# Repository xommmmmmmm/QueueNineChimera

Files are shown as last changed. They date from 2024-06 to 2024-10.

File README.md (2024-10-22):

# Q9 Chimera & Limousine

Q9 Chimera & Limousine are RP2040-based, drop-in, multi-layout replacement PCBs for Keychron Q9. Chimera supports ortholinear layout with central or right-hand numpad, and traditional row-stagger with right hand numpad. Limousine supports row and alpha stagger, with support for 2.25u/2.75u "Alice" bars and right-hand numpad.

Both versions support up to two independent EC11 rotary encoders in the separated key positions, and a plethora of bottom-row options.

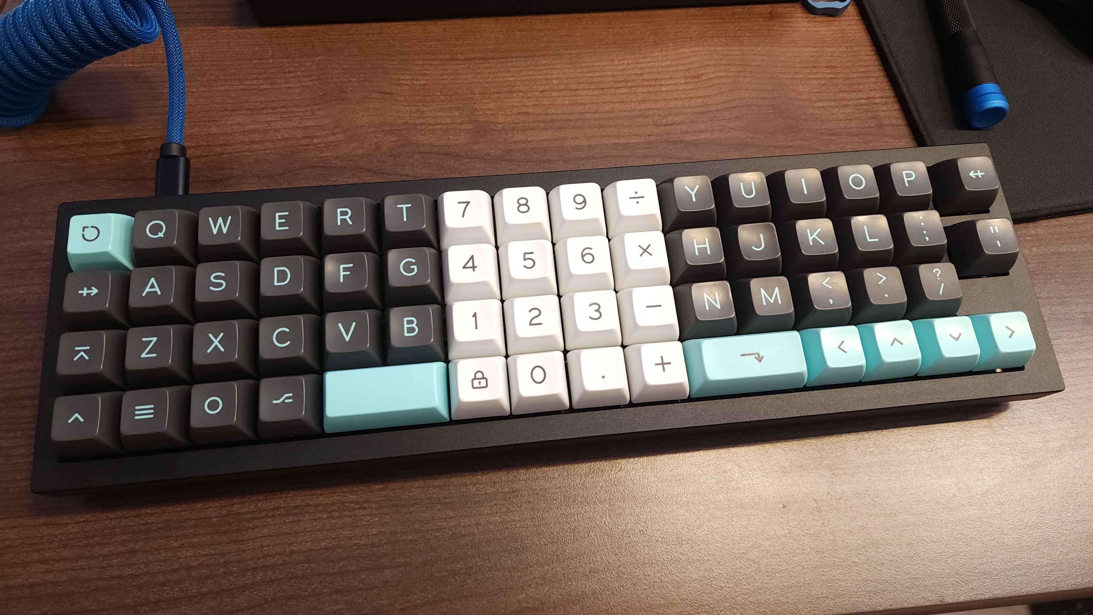
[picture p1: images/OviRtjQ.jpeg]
Q9 Chimera Ortho

*xomm's split ortho build*

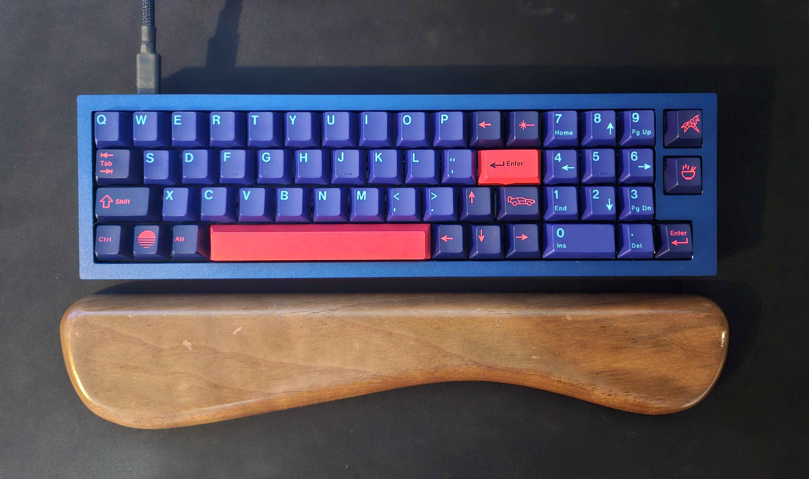
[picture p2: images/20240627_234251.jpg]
Q9 Chimera Row Stagger

*baconspoon's row-staggered build*

## Hardware

* Keyboard Maintainer: [xomm](https://github.com/xommmmmmmm) and [baconspoon](https://github.com/baconspoon85)
* Hardware Supported: Keychron Q9, Keychron Q9 Plus cases with Q9 Chimera PCB
* Hardware Availability: Case from [Keychron](https://www.keychron.com/products/keychron-q9-qmk-custom-mechanical-keyboard), Open-source PCB orderable from JLCPCB using provided production files in their respective subfolders. Production files should be orderable as-is and have been used successfully for PCBA, but no guarantees or warranties are made. 

This project is not affiliated with or endorsed by Keychron or JLCPCB.

### Build Guide

**Disassembly**:
1. If you have keycaps on the board, remove them before disassembly to avoid scratching them against the case.
1. Flip the board upside down and unscrew the six H2.5 screws on the bottom case to remove it.
1. Disconnect the JST connector from the original board
1. Lift the assembly out by lifting from the bottom (spacebar side) first, then pull it out from under the daughterboard. Take care not to lose the 3 plastic caps from the pegs on the top case.

**Test the new PCB**:
1. Insert 2 switches in the top left for unlocking the board.
1. Connect the JST from the daughterboard to the new board.
1. Taking care to not short any board components on the top case, connect the USB-C to your PC.
1. Open https://vial.rocks/ to validate that it is detected.
1. Open the matrix tester and use tweezers or a switch puller to check sockets.
1. Disconnect USB-C once done, then disconnect the JST.

**PCB Assembly**:
1. If you have a barebones PCB and/or want to add EC11 encoder(s), now is the time to solder. 
    1. If you are not using encoder(s), and you originally purchased the Q9 with one, remove the PH1 screws holding in the encoder blocker from the top case. 
1. Add any PCB-mounted stabilizers you will be using. If your switches have minimal wobble, you generally won't need 2u stabilizers.  
    1. Limousine note: If you chose to have Mill-Max sockets soldered for 3u spacebars, you will need to desolder one of the Kailh hotswap sockets to access a 3u stabilizer hole. Conversely, the 3u Mill-Max sockets sit under the stabilizers of other footprints, so you may want to add pads under your stabilizers to reduce the bottom-out noise.

**Plate Assembly**:
1. When inserting switches, support the hotswap socket from the back to avoid accidental damage in case of misalignment. Reference the KLE for your desired layout if unsure which footprints to use.
1. To align the plate, place switches around the border of the plate and a few in the top row, then assemble the plate to the PCB.
1. To minimize plate flex when inserting switches, fill out the remaining switches from right to left, top to bottom.
1. If you will be reusing the original foam gaskets, remove them carefully by picking at one side until all the adhesive is lifted, then slowly peel it off the plate.
1. If you will be using the included gaskets from the kit, they are unfortunately short, but will function and sound pretty much the same.
    1. You can choose to use them as-is and stick them in the middle, or cut them in half and stick them on the edges.
1. Apply the gaskets on both sides of the plate (eight total), using tweezers is recommended.

**Case Assembly**:
1. Insert the assembly into the top case, putting the top under the daughterboard first, then aligning the mounting holes on the plate with the pegs in the top case. Pay attention to the six screw posts since they might catch on their cutouts in plate a bit. There might be a little bit of friction at first but it will seat once everything is aligned, heavy force is not required. 
1. Tape modding the bottom of the PCB or the inside of the bottom case, either with the stock cardboard adhesive and/or 3M painter's tape is highly recommended. This will prevent unlikely but possible shorts from bottoming out the PCB on aftermarket gaskets if you press hard.
1. Close the bottom case, add keycaps, set up your layout in Vial.
    1. In Vial, use the Layouts tab to select the physical layout options you want. For the 8u/10u spacebar option on Chimera v1.1, select the first 6u bar option and simply leave the unused keys blank.
3. Enjoy! (And maybe send a pic of your completed build in the mini-GB channel on the 40% Keyboards Discord server!)

## Firmware

PCBs purchases from the mini-GB are pre-flashed. Vial firmware source can be found [here](https://github.com/xommmmmmmm/vial-qmk/tree/q9_chimera_v1.1/keyboards/q9_dropin). Pre-compiled firmware can be found [here](https://github.com/xommmmmmmm/QueueNineChimera/tree/main/firmware/). 

# Q9 Chimera keymap options

All sockets for all layout options can be populated during PCB assembly, including the ones under the encoders.

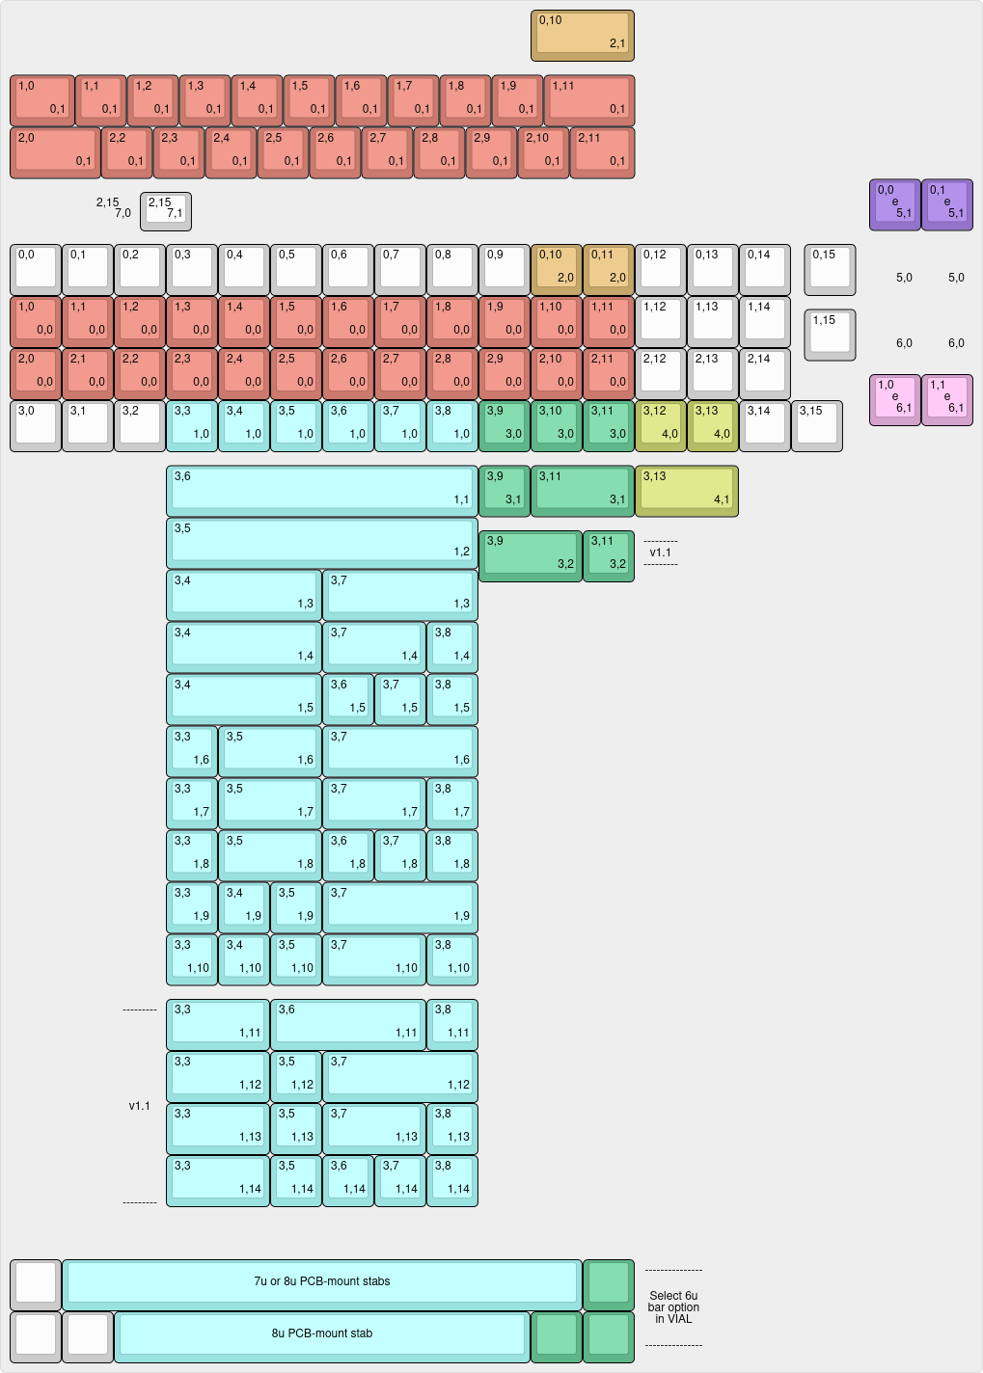
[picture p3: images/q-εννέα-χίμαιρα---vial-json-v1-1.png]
Q9 Chimera v1.1 keymap options

- [Chimera v1.0 Keyboard Layout Editor gist](https://www.keyboard-layout-editor.com/#/gists/b5c5bf3bcd11c2a14bd86eb9c05d4cf7)
- [Chimera v1.1 Keyboard Layout Editor gist](https://www.keyboard-layout-editor.com/#/gists/ead72f9d526c6d2558d7e2d7f39707f8)

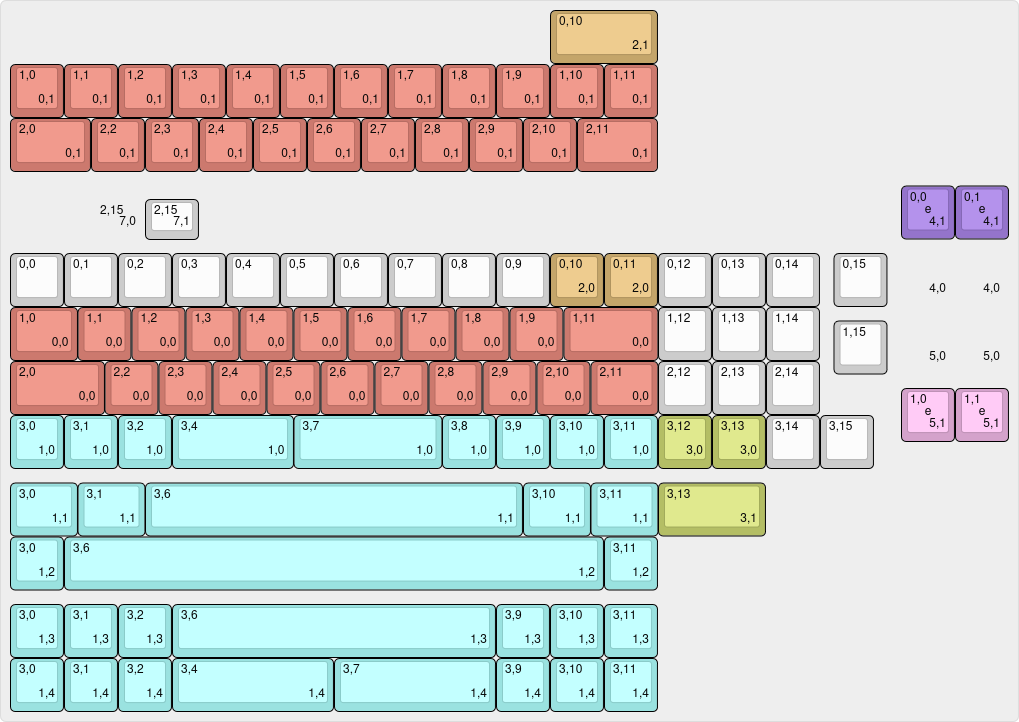
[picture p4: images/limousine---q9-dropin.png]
Q9 Limousine v1.0 keymap options

- [Limousine v1.0 Keyboard Layout Editor gist](https://www.keyboard-layout-editor.com/#/gists/2bb4640f105051db48f84b30d6797b1b)

## Options

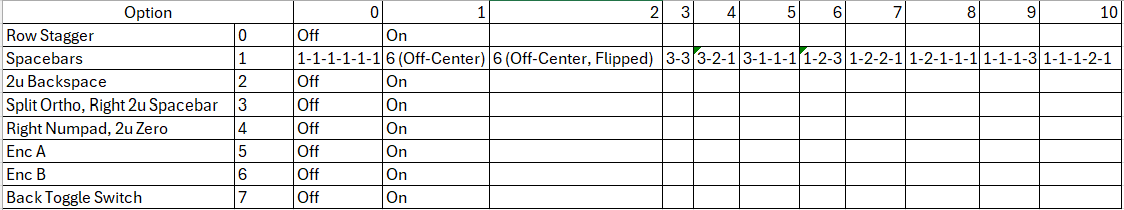
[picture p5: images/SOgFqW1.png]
Q9 Chimera keymap option names


The images at the top use the following options:
- xomm's split ortho layout:
  - Spacebar option 8: 1-2-1-1-1
  - Split Ortho, Right 2u Spacebar
- baconspoon's row-staggered layout:
  - Row Stagger
  - Spacebar option 2: 6 (off-center, flipped)
  - Right Numpad, 2u Zero

The default keymap is provided as barebones due to the number of possible layouts, and should be edited as desired. Remember to export your .vil from Vial GUI once satisfied for safekeeping.

## Credits and helpful things

- Big thanks to baconspoon for validating the design, contributing plate/edge cuts, additional layouts, and a ton of other help.
- Noah Kiser's [TKL RP2040 PCB Design](https://www.youtube.com/watch?v=6Z49bynRqj8&list=PLstjCi968EZftHZSitvqiVnyZ1CbmptIB) series
- Joe Scotto's [PCB Design](https://www.youtube.com/watch?v=7LyziNdFlew&list=PLBD2IS_t_iWZDMdG_ZF57x9Ebm3kxKqxF) series

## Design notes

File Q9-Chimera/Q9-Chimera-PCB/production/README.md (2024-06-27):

# JLCPCB Order Information

These were the settings used for the original production run for personal use. The PCB files have been updated since the first run to correct some solder mask issues based on JLC engineers' advice, and should be able to be ordered as-is, but no guarantees or warranties are made.

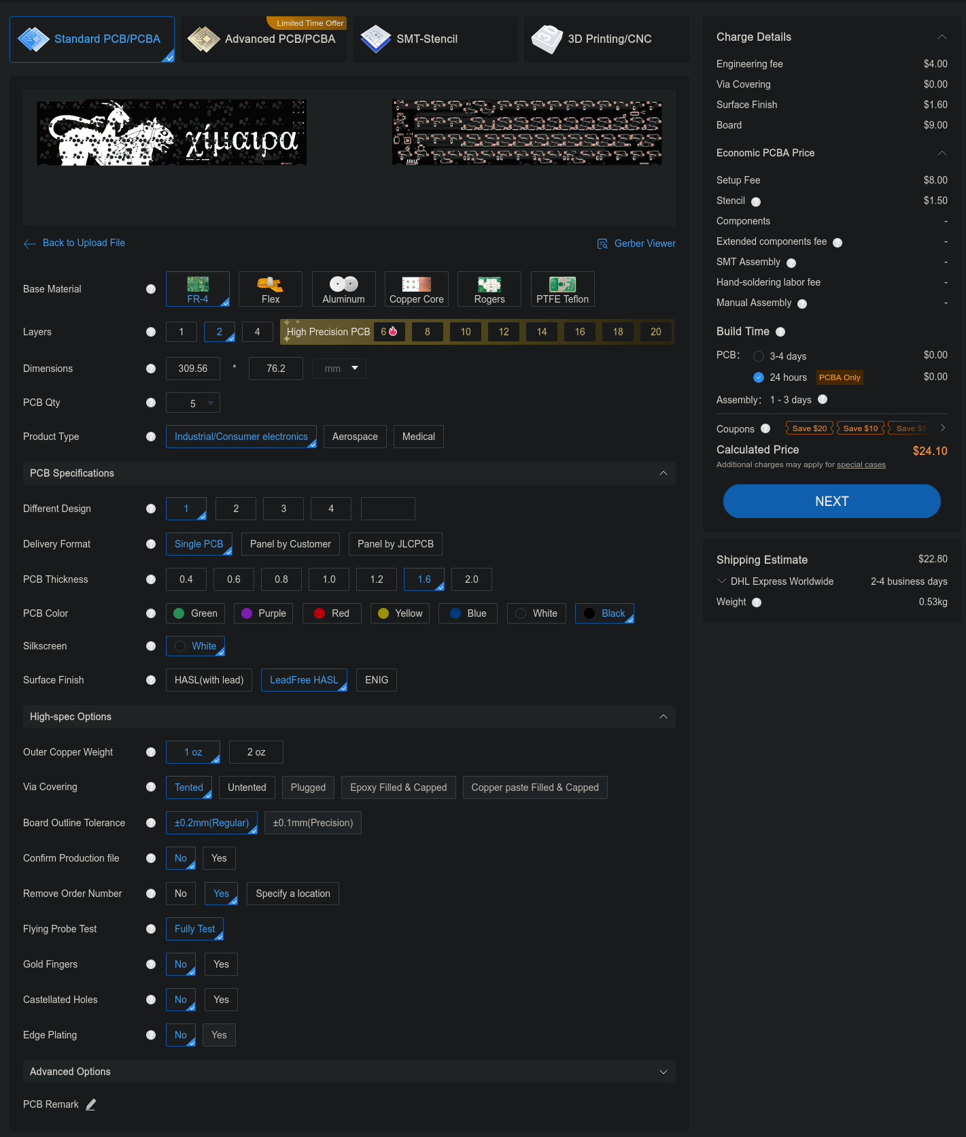
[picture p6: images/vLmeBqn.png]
JLCPCB1

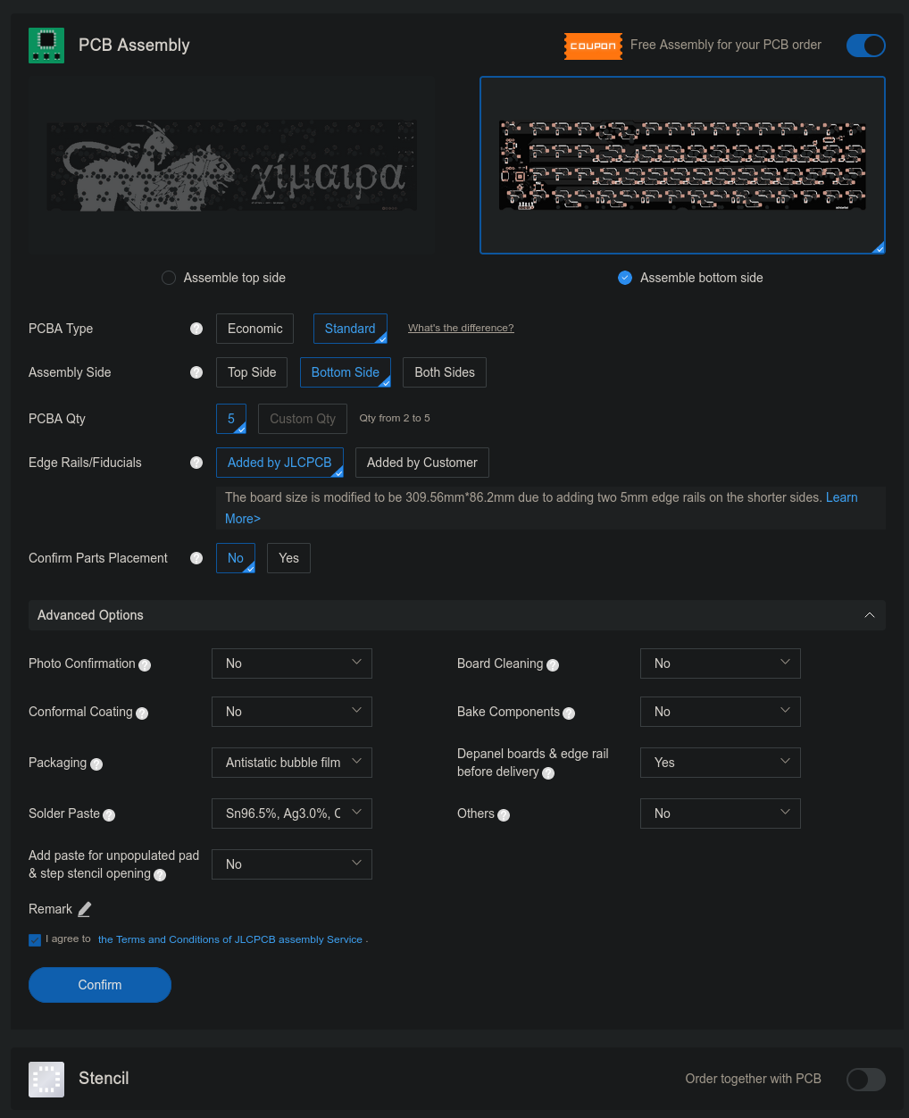
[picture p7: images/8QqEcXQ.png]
JLCPCB2

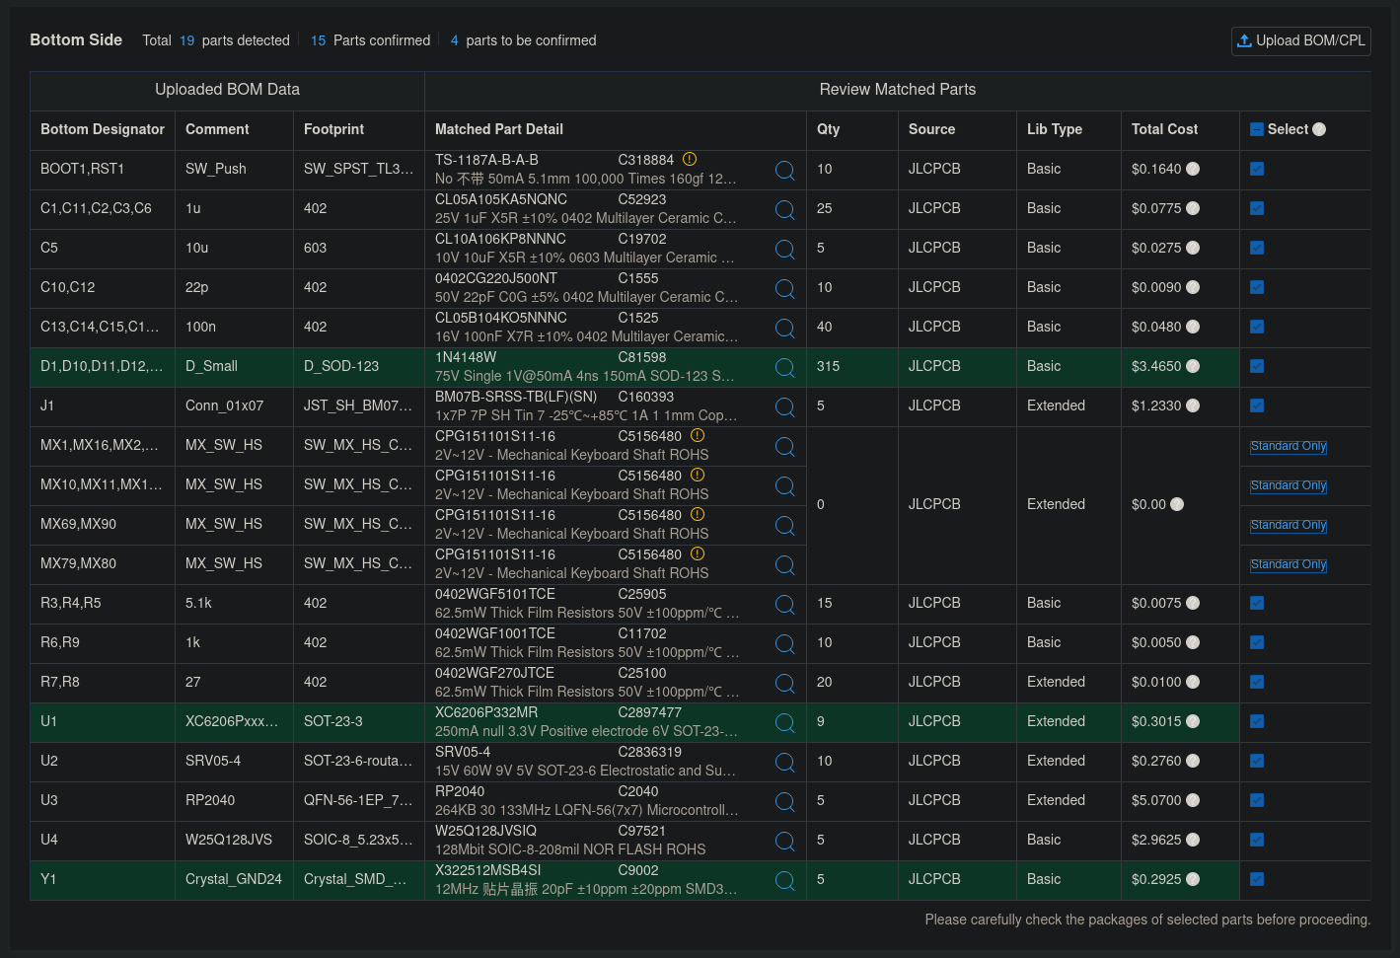
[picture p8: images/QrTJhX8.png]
JLCPCB3

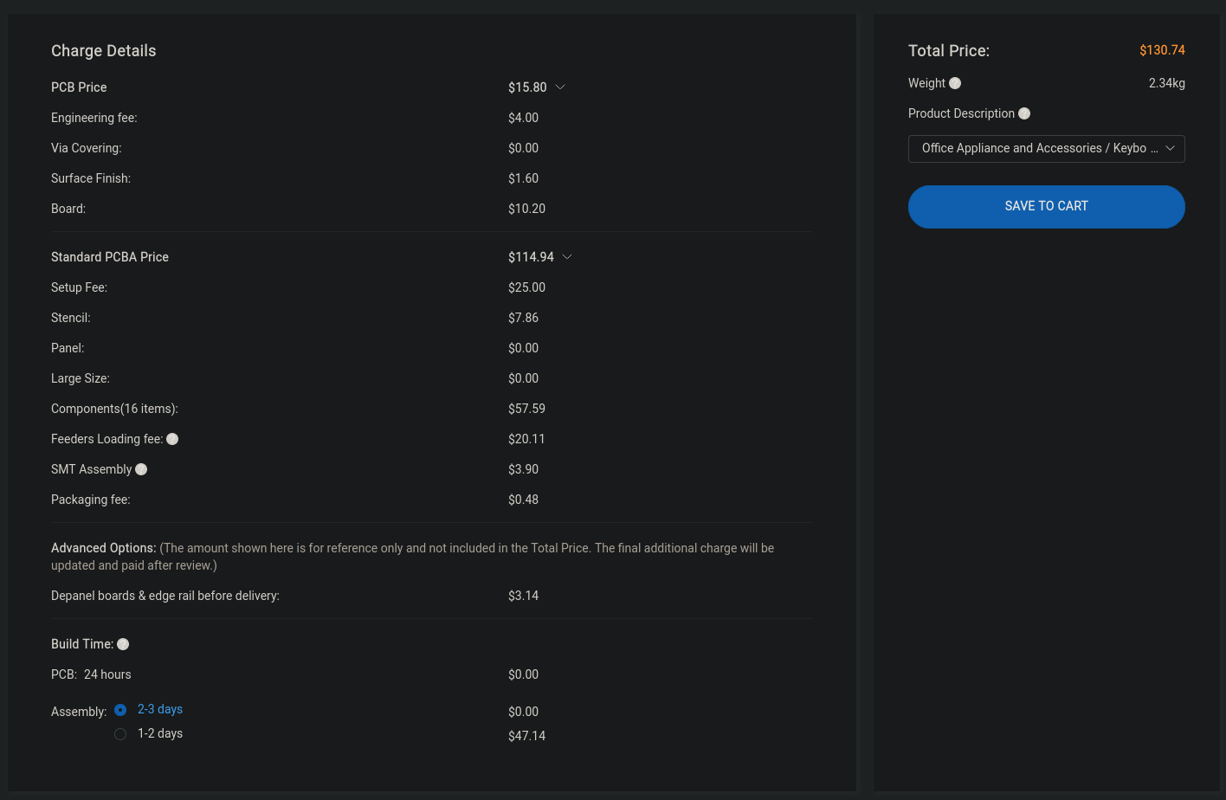
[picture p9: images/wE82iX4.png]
JLCPCB4


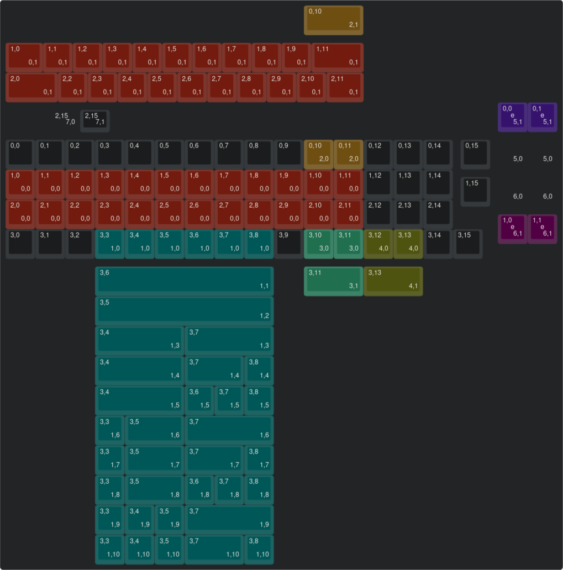
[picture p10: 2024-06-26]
images/q-εννέα-χίμαιρα---vial-json.png

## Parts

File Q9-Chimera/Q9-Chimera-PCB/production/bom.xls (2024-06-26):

Comment | Designator | Footprint | JLCPCB Part #
D_Small | D1,D10,D11,D12,D13,D14,D15,D16,D17,D18,D19,D2,D20,D21,D22,D23,D24,D25,D26,D27,D28,D29,D3,D30,D31,D32,D33,D34,D35,D36,D37,D38,D39,D4,D40,D41,D42,D43,D44,D45,D46,D47,D48,D49,D5,D50,D51,D52,D54,D55,D56,D57,D58,D59,D6,D61,D62,D63,D64,D65,D7,D8,D9 | D_SOD-123 | C81598
SW_Push | BOOT1,RST1 | SW_SPST_TL3342 | C318884
SRV05-4 | U2 | SOT-23-6-routable | C2836319
10u | C5 | 603 | C19702
Crystal_GND24 | Y1 | Crystal_SMD_3225-4Pin_3.2x2.5mm | C403945
27 | R7,R8 | 402 | C25100
MX_SW_HS | MX79,MX80,MX69,MX90,MX10,MX11,MX12,MX13,MX14,MX15,MX17,MX18,MX19,MX20,MX21,MX22,MX23,MX24,MX25,MX26,MX27,MX28,MX29,MX30,MX31,MX33,MX34,MX35,MX36,MX37,MX38,MX39,MX4,MX40,MX41,MX42,MX43,MX44,MX45,MX46,MX47,MX48,MX49,MX5,MX50,MX51,MX52,MX53,MX54,MX55,MX56,MX57,MX58,MX59,MX6,MX60,MX61,MX62,MX63,MX64,MX65,MX66,MX67,MX68,MX7,MX70,MX71,MX72,MX73,MX74,MX75,MX76,MX77,MX78,MX8,MX81,MX82,MX83,MX84,MX85,MX86,MX87,MX88,MX89,MX9,MX1,MX16,MX2,MX3,MX32 | SW_MX_HS_CPG151101S11_1u | C5156480
XC6206PxxxMR | U1 | SOT-23-3 | C2897477
100n | C13,C14,C15,C16,C4,C7,C8,C9 | 402 | C1525
22p | C10,C12 | 402 | C1555
5.1k | R3,R4,R5 | 402 | C25905
1u | C1,C11,C2,C3,C6 | 402 | C52923
Conn_01x07 | J1 | JST_SH_BM07B-SRSS-TB_1x07-1MP_P1.00mm_Vertical | C160393
W25Q128JVS | U4 | SOIC-8_5.23x5.23mm_P1.27mm | C97521
1k | R6,R9 | 402 | C11702
RP2040 | U3 | QFN-56-1EP_7x7mm_P0.4mm_EP3.2x3.2mm | C2040

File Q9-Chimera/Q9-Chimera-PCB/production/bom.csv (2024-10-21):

Designator | Footprint | Quantity | Value | LCSC Part #
BOOT1, RST1 | SW_SPST_TL3342 | 2 | SW_Push
C1, C11, C2, C3, C6 | 0402 | 5 | 1u
C10, C12 | 0402 | 2 | 22p
C13, C14, C15, C16, C4, C7, C8, C9 | 0402 | 8 | 100n
C5 | 0603 | 1 | 10u
D1, D10, D11, D12, D13, D14, D15, D16, D17, D18, D19, D2, D20, D21, D22, D23, D24, D25, D26, D27, D28, D29, D3, D30, D31, D32, D33, D34, D35, D36, D37, D38, D39, D4, D40, D41, D42, D43, D44, D45, D46, D47, D48, D49, D5, D50, D51, D52, D54, D55, D56, D57, D58, D59, D6, D61, D62, D63, D64, D65, D7, D8, D9 | D_SOD-123_xomm | 63 | D_Small
J1 | JST_SH_BM07B-SRSS-TB_1x07-1MP_P1.00mm_Vertical | 1 | Conn_01x07 | C160393
MX1, MX16, MX2, MX3, MX32 | SW_MX_HS_S_CPG151101S11_1u | 5 | MX_SW_HS
MX10, MX11, MX12, MX13, MX14, MX15, MX17, MX18, MX19, MX20, MX21, MX22, MX23, MX24, MX25, MX26, MX27, MX28, MX29, MX30, MX31, MX33, MX34, MX35, MX36, MX37, MX38, MX39, MX4, MX40, MX41, MX42, MX43, MX44, MX45, MX46, MX47, MX48, MX49, MX5, MX50, MX51, MX52, MX54, MX55, MX56, MX57, MX58, MX59, MX6, MX61, MX62, MX63, MX64, MX65, MX66, MX67, MX68, MX7, MX70, MX71, MX72, MX73, MX74, MX75, MX76, MX77, MX78, MX8, MX81, MX82, MX83, MX84, MX85, MX86, MX87, MX88, MX89, MX9, MX91, MX92 | SW_MX_HS_CPG151101S11_1u | 81 | MX_SW_HS
MX53, MX60, MX95 | SW_MX_1u | 3 | MX_SW_HS
MX69, MX90 | SW_MX_HS_CPG151101S11_1.25u | 2 | MX_SW_HS
MX79, MX80 | SW_MX_HS_CPG151101S11_1.75u | 2 | MX_SW_HS
R3, R4, R5 | 0402 | 3 | 5.1k
R6, R9 | 0402 | 2 | 1k
R7, R8 | 0402 | 2 | 27
S1, S2, S3, S4, S7, S8, S9 | STAB_MX_2u | 7 | MX_stab_2u
S10, S5, S6 | STAB_MX_3u | 3 | MX_stab_3u
S13 | STAB_MX_10u | 1 | MX_stab_7810u
U1 | SOT-23-3 | 1 | XC6206PxxxMR | C2897477
U2 | SOT-23-6-routable | 1 | SRV05-4 | C2836319
U3 | QFN-56-1EP_7x7mm_P0.4mm_EP3.2x3.2mm | 1 | RP2040 | C2040
U4 | SOIC-8_5.23x5.23mm_P1.27mm | 1 | W25Q128JVS | C97521
Y1 | Crystal_SMD_3225-4Pin_3.2x2.5mm | 1 | Crystal_GND24 | C403945

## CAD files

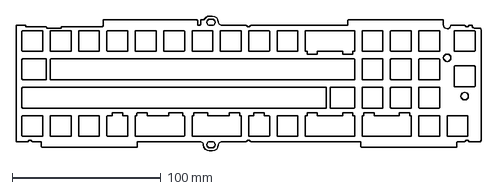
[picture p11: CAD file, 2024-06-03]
Q9-Chimera/Q9-Chimera-Plate/q9-chimera-plate.dxf
312.5 x 90.5 mm

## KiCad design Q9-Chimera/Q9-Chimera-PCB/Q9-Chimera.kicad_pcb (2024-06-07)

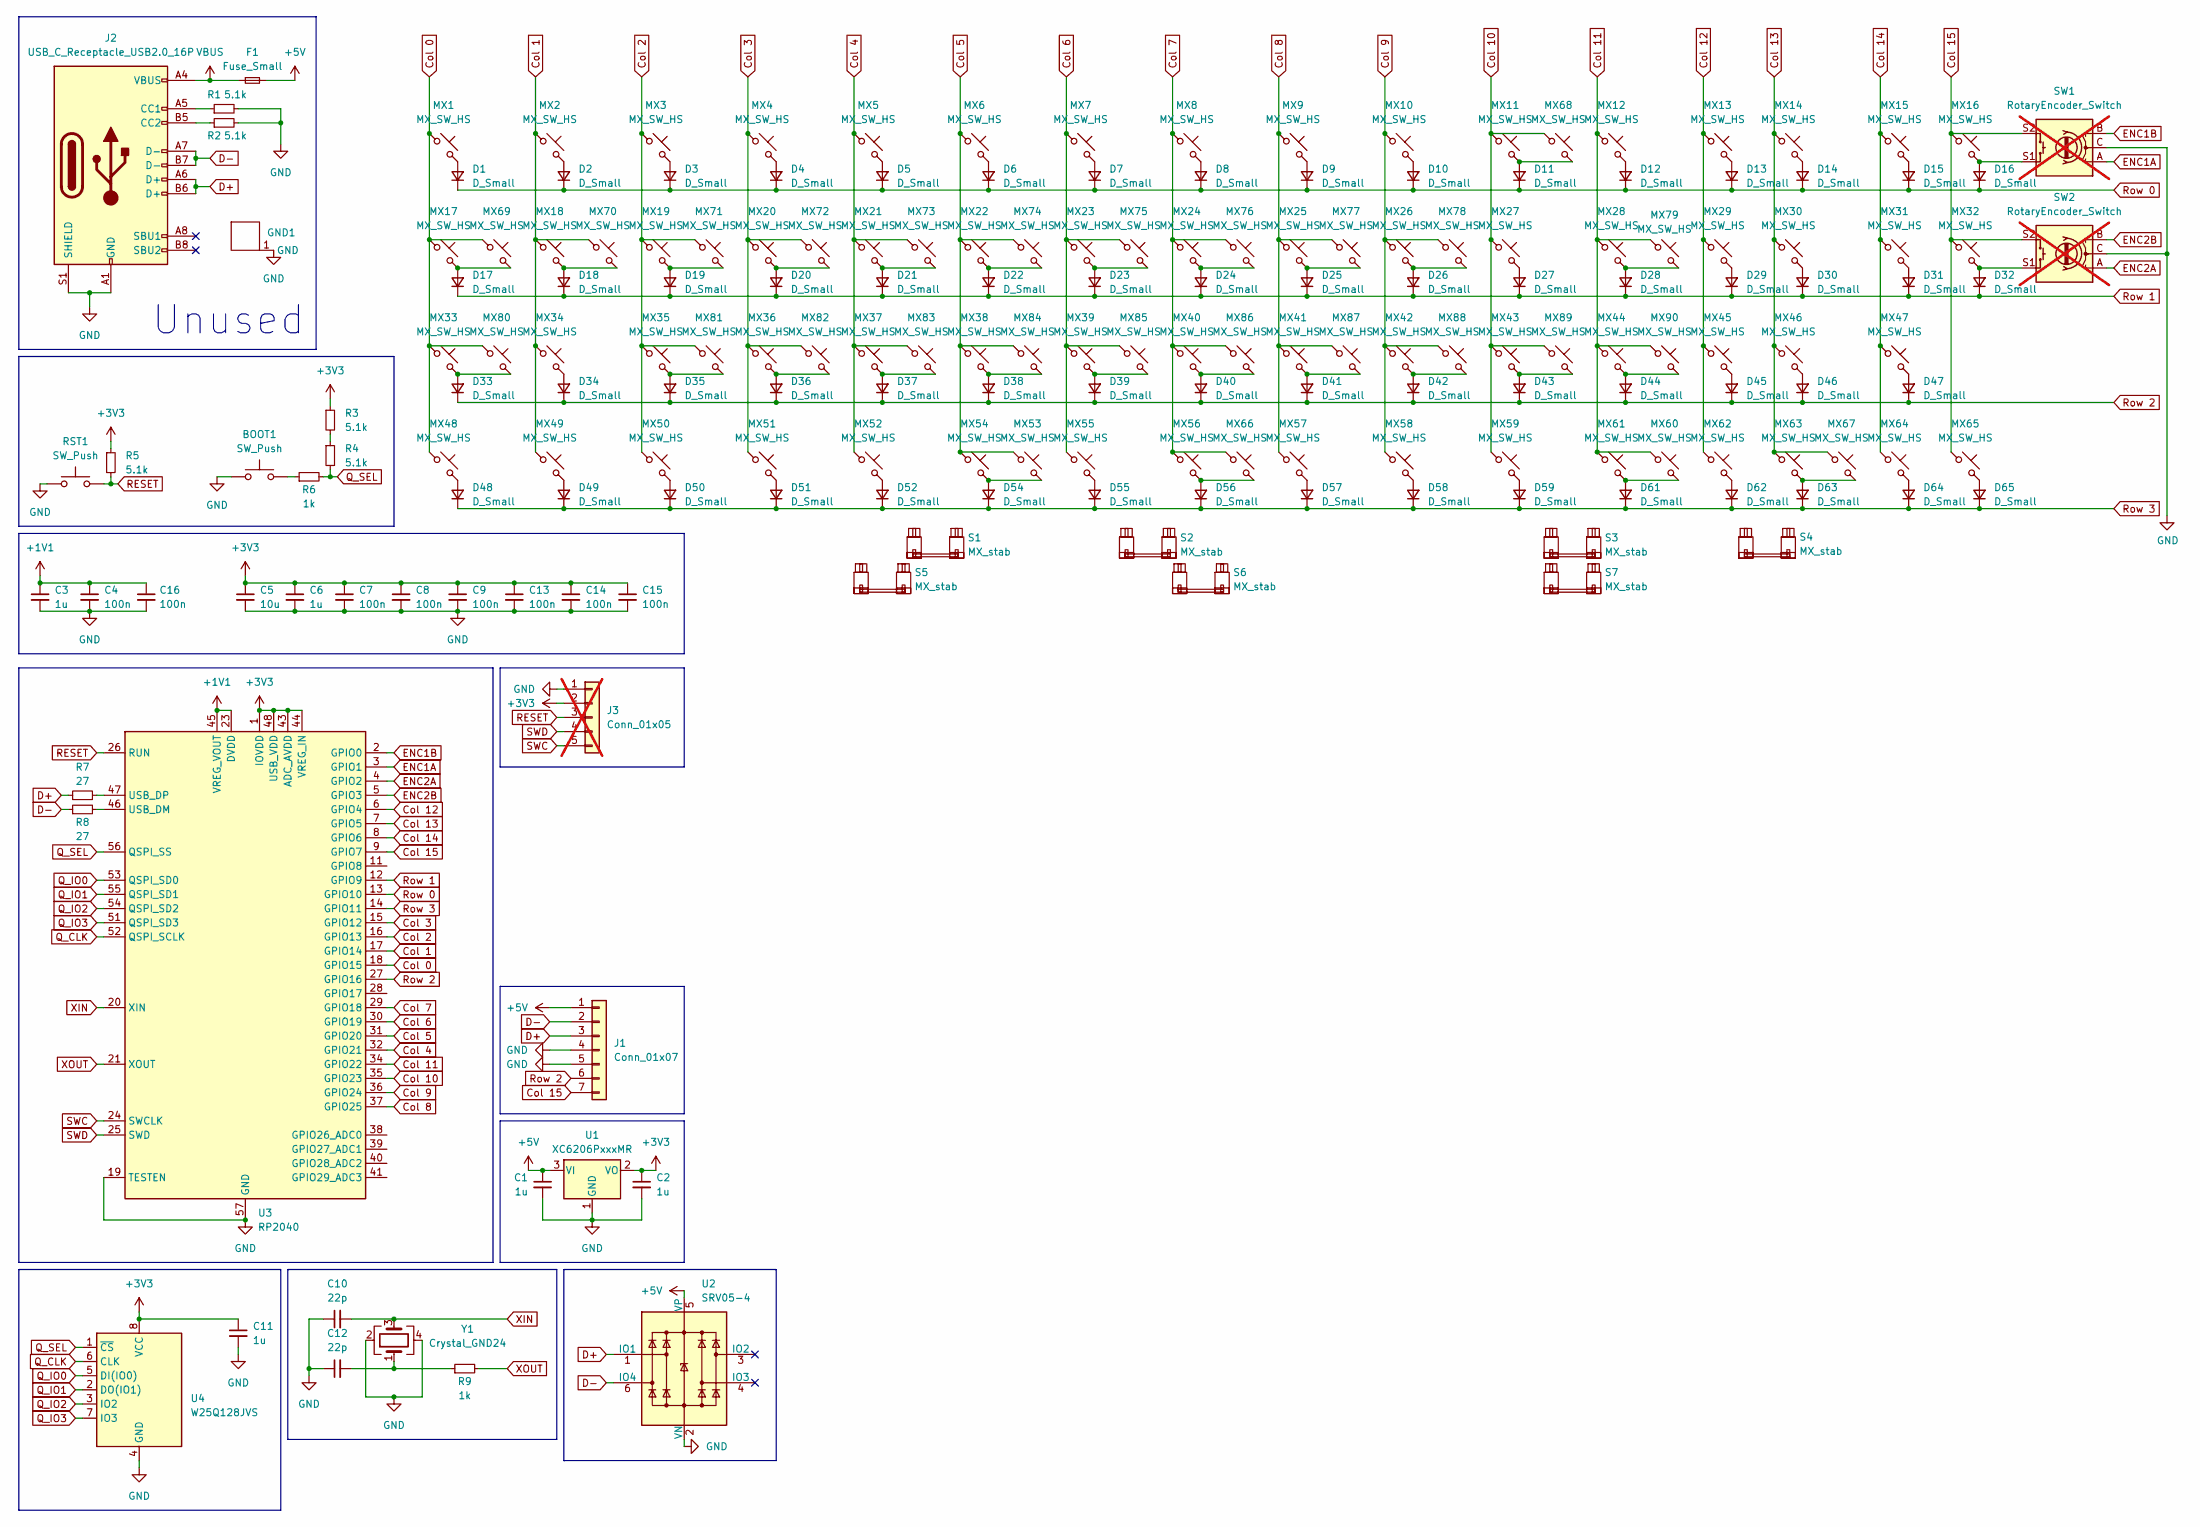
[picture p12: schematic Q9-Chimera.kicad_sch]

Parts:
BOOT1: SW_Push; SW_SPST_TL3342
C1, C2, C3, C6, C11: 1u; C_0402_1005Metric
C4, C7, C8, C9, C13, C14, C15, C16: 100n; C_0402_1005Metric
C5: 10u; C_0603_1608Metric
C10, C12: 22p; C_0402_1005Metric
D1, D2, D3, D4, D5, D6, D7, D8, D9, D10, D11, D12, D13, D14, D15, D16, D17, D18, D19, D20, D21, D22, D23, D24, D25, D26, D27, D28, D29, D30, D31, D32, D33, D34, D35, D36, D37, D38, D39, D40, D41, D42, D43, D44, D45, D46, D47, D48, D49, D50, D51, D52, D54, D55, D56, D57, D58, D59, D61, D62, D63, D64, D65: D_Small; D_SOD-123_xomm
F1: Fuse_Small; Fuse_1206_3216Metric
GND1: LargeGroundPad
J1: Conn_01x07; JST_SH_BM07B-SRSS-TB_1x07-1MP_P1.00mm_Vertical
J2: USB_C_Receptacle_USB2.0_16P; USB_C_Receptacle_HRO_TYPE-C-31-M-12
J3: Conn_01x05; PinHeader_1x05_P2.54mm_Vertical; not fitted
MX1, MX2, MX3, MX16, MX32: MX_SW_HS; SW_MX_HS_S_CPG151101S11_1u
MX4, MX5, MX6, MX7, MX8, MX9, MX10, MX11, MX12, MX13, MX14, MX15, MX17, MX18, MX19, MX20, MX21, MX22, MX23, MX24, MX25, MX26, MX27, MX28, MX29, MX30, MX31, MX33, MX34, MX35, MX36, MX37, MX38, MX39, MX40, MX41, MX42, MX43, MX44, MX45, MX46, MX47, MX48, MX49, MX50, MX51, MX52, MX53, MX54, MX55, MX56, MX57, MX58, MX59, MX60, MX61, MX62, MX63, MX64, MX65, MX66, MX67, MX68, MX70, MX71, MX72, MX73, MX74, MX75, MX76, MX77, MX78, MX81, MX82, MX83, MX84, MX85, MX86, MX87, MX88, MX89: MX_SW_HS; SW_MX_HS_CPG151101S11_1u
MX69, MX90: MX_SW_HS; SW_MX_HS_CPG151101S11_1.25u
MX79, MX80: MX_SW_HS; SW_MX_HS_CPG151101S11_1.75u
R1, R2, R3, R4, R5: 5.1k; R_0402_1005Metric
R6, R9: 1k; R_0402_1005Metric
R7, R8: 27; R_0402_1005Metric
RST1: SW_Push; SW_SPST_TL3342
S1, S2, S3, S4, S7: MX_stab; STAB_MX_2u
S5, S6: MX_stab; STAB_MX_3u
SW1, SW2: RotaryEncoder_Switch; ROT_Alps_EC11E-Switch; not fitted
U1: XC6206PxxxMR; SOT-23-3
U2: SRV05-4; SOT-23-6-routable
U3: RP2040; QFN-56-1EP_7x7mm_P0.4mm_EP3.2x3.2mm
U4: W25Q128JVS; SOIC-8_5.23x5.23mm_P1.27mm
Y1: Crystal_GND24; Crystal_SMD_3225-4Pin_3.2x2.5mm

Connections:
+1V1: C3.1, C4.1, C16.1, U3.23 (DVDD), U3.45 (VREG_VOUT), U3.50 (DVDD)
+3V3: C2.1, C5.1, C6.1, C7.1, C8.1, C9.1, C11.1, C13.1, C14.1, C15.1, J3.2, R3.1, R5.1, U1.2 (VO), U3.1 (IOVDD), U3.10 (IOVDD), U3.22 (IOVDD), U3.33 (IOVDD), U3.42 (IOVDD), U3.43 (ADC_AVDD), U3.44 (VREG_IN), U3.48 (USB_VDD), U3.49 (IOVDD), U4.8 (VCC)
+5V: C1.1, F1.2, J1.1, U1.3 (VI), U2.5 (VP)
Col 0: MX1.1, MX17.1, MX33.1, MX48.1, MX69.1, MX80.1, U3.18 (GPIO15)
Col 1: MX2.1, MX18.1, MX34.1, MX49.1, MX70.1, U3.17 (GPIO14)
Col 2: MX3.1, MX19.1, MX35.1, MX50.1, MX71.1, MX81.1, U3.16 (GPIO13)
Col 3: MX4.1, MX20.1, MX36.1, MX51.1, MX72.1, MX82.1, U3.15 (GPIO12)
Col 4: MX5.1, MX21.1, MX37.1, MX52.1, MX73.1, MX83.1, U3.32 (GPIO21)
Col 5: MX6.1, MX22.1, MX38.1, MX53.1, MX54.1, MX74.1, MX84.1, U3.31 (GPIO20)
Col 6: MX7.1, MX23.1, MX39.1, MX55.1, MX75.1, MX85.1, U3.30 (GPIO19)
Col 7: MX8.1, MX24.1, MX40.1, MX56.1, MX66.1, MX76.1, MX86.1, U3.29 (GPIO18)
Col 8: MX9.1, MX25.1, MX41.1, MX57.1, MX77.1, MX87.1, U3.37 (GPIO25)
Col 9: MX10.1, MX26.1, MX42.1, MX58.1, MX78.1, MX88.1, U3.36 (GPIO24)
Col 10: MX11.1, MX27.1, MX43.1, MX59.1, MX68.1, MX89.1, U3.35 (GPIO23)
Col 11: MX12.1, MX28.1, MX44.1, MX60.1, MX61.1, MX79.1, MX90.1, U3.34 (GPIO22)
Col 12: MX13.1, MX29.1, MX45.1, MX62.1, U3.6 (GPIO4)
Col 13: MX14.1, MX30.1, MX46.1, MX63.1, MX67.1, U3.7 (GPIO5)
Col 14: MX15.1, MX31.1, MX47.1, MX64.1, U3.8 (GPIO6)
Col 15: J1.7, MX16.1, MX32.1, MX65.1, SW1.S2, SW2.S2, U3.9 (GPIO7)
D+: J1.3, J2.A6 (D+), J2.B6 (D+), R7.1, U2.1 (IO1)
D-: J1.2, J2.A7 (D-), J2.B7 (D-), R8.1, U2.6 (IO4)
ENC1A: SW1.A, U3.3 (GPIO1)
ENC1B: SW1.B, U3.2 (GPIO0)
ENC2A: SW2.A, U3.4 (GPIO2)
ENC2B: SW2.B, U3.5 (GPIO3)
GND: BOOT1.1, C1.2, C2.2, C3.2, C4.2, C5.2, C6.2, C7.2, C8.2, C9.2, C10.1, C11.2, C12.1, C13.2, C14.2, C15.2, C16.2, J1.4, J1.5, J2.A1 (GND), J2.A12 (GND), J2.B1 (GND), J2.B12 (GND), J2.S1 (SHIELD), J3.1, R1.2, R2.2, RST1.1, SW1.C, SW2.C, U1.1 (GND), U2.2 (VN), U3.19 (TESTEN), U3.57 (GND), U4.4 (GND), Y1.2, Y1.4
unnamed: BOOT1.2, R6.1
unnamed: C12.2, R9.1, Y1.1
unnamed: D1.2 (A), MX1.2
unnamed: D2.2 (A), MX2.2
unnamed: D3.2 (A), MX3.2
unnamed: D4.2 (A), MX4.2
unnamed: D5.2 (A), MX5.2
unnamed: D6.2 (A), MX6.2
unnamed: D7.2 (A), MX7.2
unnamed: D8.2 (A), MX8.2
unnamed: D9.2 (A), MX9.2
unnamed: D10.2 (A), MX10.2
unnamed: D11.2 (A), MX11.2, MX68.2
unnamed: D12.2 (A), MX12.2
unnamed: D13.2 (A), MX13.2
unnamed: D14.2 (A), MX14.2
unnamed: D15.2 (A), MX15.2
unnamed: D16.2 (A), MX16.2, SW1.S1
unnamed: D17.2 (A), MX17.2, MX69.2
unnamed: D18.2 (A), MX18.2, MX70.2
unnamed: D19.2 (A), MX19.2, MX71.2
unnamed: D20.2 (A), MX20.2, MX72.2
unnamed: D21.2 (A), MX21.2, MX73.2
unnamed: D22.2 (A), MX22.2, MX74.2
unnamed: D23.2 (A), MX23.2, MX75.2
unnamed: D24.2 (A), MX24.2, MX76.2
unnamed: D25.2 (A), MX25.2, MX77.2
unnamed: D26.2 (A), MX26.2, MX78.2
unnamed: D27.2 (A), MX27.2
unnamed: D28.2 (A), MX28.2, MX79.2
unnamed: D29.2 (A), MX29.2
unnamed: D30.2 (A), MX30.2
unnamed: D31.2 (A), MX31.2
unnamed: D32.2 (A), MX32.2, SW2.S1
unnamed: D33.2 (A), MX33.2, MX80.2
unnamed: D34.2 (A), MX34.2
unnamed: D35.2 (A), MX35.2, MX81.2
unnamed: D36.2 (A), MX36.2, MX82.2
unnamed: D37.2 (A), MX37.2, MX83.2
unnamed: D38.2 (A), MX38.2, MX84.2
unnamed: D39.2 (A), MX39.2, MX85.2
unnamed: D40.2 (A), MX40.2, MX86.2
unnamed: D41.2 (A), MX41.2, MX87.2
unnamed: D42.2 (A), MX42.2, MX88.2
unnamed: D43.2 (A), MX43.2, MX89.2
unnamed: D44.2 (A), MX44.2, MX90.2
unnamed: D45.2 (A), MX45.2
unnamed: D46.2 (A), MX46.2
unnamed: D47.2 (A), MX47.2
unnamed: D48.2 (A), MX48.2
unnamed: D49.2 (A), MX49.2
unnamed: D50.2 (A), MX50.2
unnamed: D51.2 (A), MX51.2
unnamed: D52.2 (A), MX52.2
unnamed: D54.2 (A), MX53.2, MX54.2
unnamed: D55.2 (A), MX55.2
unnamed: D56.2 (A), MX56.2, MX66.2
unnamed: D57.2 (A), MX57.2
unnamed: D58.2 (A), MX58.2
unnamed: D59.2 (A), MX59.2
unnamed: D61.2 (A), MX60.2, MX61.2
unnamed: D62.2 (A), MX62.2
unnamed: D63.2 (A), MX63.2, MX67.2
unnamed: D64.2 (A), MX64.2
unnamed: D65.2 (A), MX65.2
unnamed: F1.1, J2.A4 (VBUS), J2.A9 (VBUS), J2.B4 (VBUS), J2.B9 (VBUS)
unnamed: J2.A5 (CC1), R1.1
unnamed: J2.B5 (CC2), R2.1
unnamed: R3.2, R4.1
unnamed: R8.2, U3.46 (USB_DM)
unnamed: R7.2, U3.47 (USB_DP)
Q_CLK: U3.52 (QSPI_SCLK), U4.6 (CLK)
Q_IO0: U3.53 (QSPI_SD0), U4.5 (DI(IO0))
Q_IO1: U3.55 (QSPI_SD1), U4.2 (DO(IO1))
Q_IO2: U3.54 (QSPI_SD2), U4.3 (IO2)
Q_IO3: U3.51 (QSPI_SD3), U4.7 (IO3)
Q_SEL: R4.2, R6.2, U3.56 (QSPI_SS), U4.1 (~CS)
RESET: J3.3, R5.2, RST1.2, U3.26 (RUN)
Row 0: D1.1 (K), D2.1 (K), D3.1 (K), D4.1 (K), D5.1 (K), D6.1 (K), D7.1 (K), D8.1 (K), D9.1 (K), D10.1 (K), D11.1 (K), D12.1 (K), D13.1 (K), D14.1 (K), D15.1 (K), D16.1 (K), U3.13 (GPIO10)
Row 1: D17.1 (K), D18.1 (K), D19.1 (K), D20.1 (K), D21.1 (K), D22.1 (K), D23.1 (K), D24.1 (K), D25.1 (K), D26.1 (K), D27.1 (K), D28.1 (K), D29.1 (K), D30.1 (K), D31.1 (K), D32.1 (K), U3.12 (GPIO9)
Row 2: D33.1 (K), D34.1 (K), D35.1 (K), D36.1 (K), D37.1 (K), D38.1 (K), D39.1 (K), D40.1 (K), D41.1 (K), D42.1 (K), D43.1 (K), D44.1 (K), D45.1 (K), D46.1 (K), D47.1 (K), J1.6, U3.27 (GPIO16)
Row 3: D48.1 (K), D49.1 (K), D50.1 (K), D51.1 (K), D52.1 (K), D54.1 (K), D55.1 (K), D56.1 (K), D57.1 (K), D58.1 (K), D59.1 (K), D61.1 (K), D62.1 (K), D63.1 (K), D64.1 (K), D65.1 (K), U3.14 (GPIO11)
SWC: J3.5, U3.24 (SWCLK)
SWD: J3.4, U3.25 (SWD)
XIN: C10.2, U3.20 (XIN), Y1.3
XOUT: R9.2, U3.21 (XOUT)

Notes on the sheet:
Unused

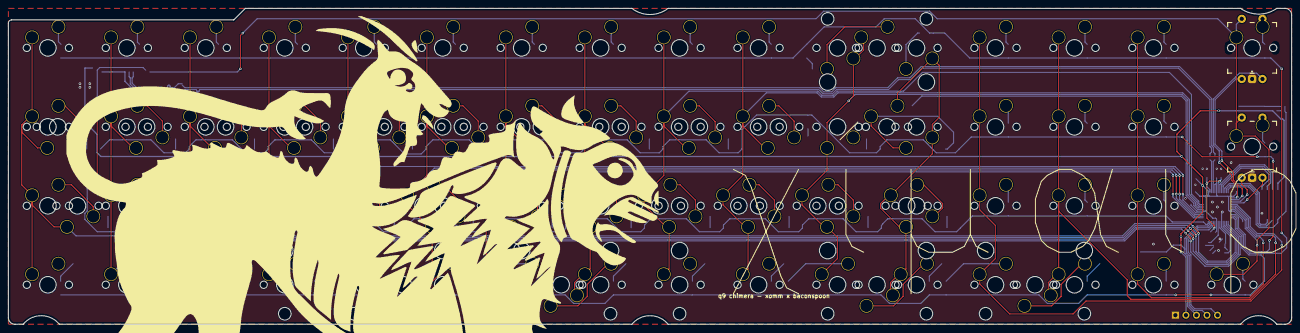
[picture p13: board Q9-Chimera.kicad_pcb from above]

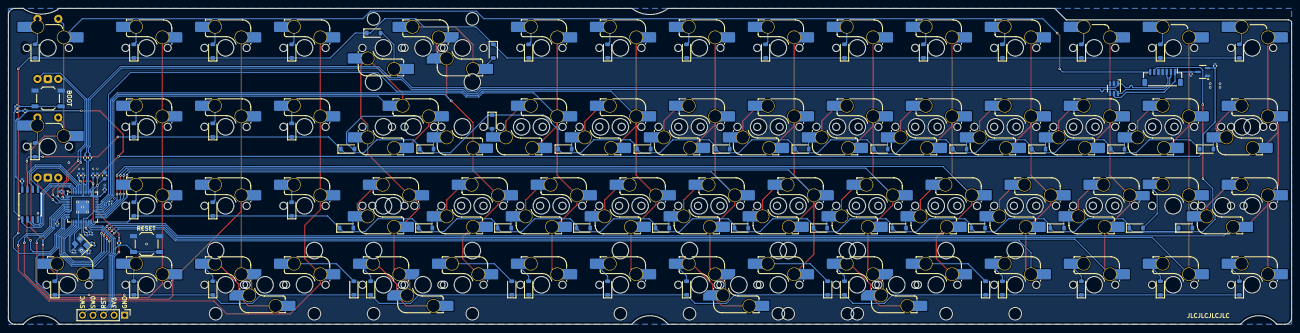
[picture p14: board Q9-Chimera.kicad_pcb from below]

Board: 2 copper layers, 309.6 x 76.2 mm, 194 parts (185 on the bottom side), 109 nets.

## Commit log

2024-05-30 add encoders, ground fill, production files
    [KeychronQ9OrthoIntegrated-B_Courtyard.gbr, KeychronQ9OrthoIntegrated-B_Cu.gbl, KeychronQ9OrthoIntegrated-B_Fab.gbr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]
2024-05-30 trach connect
    [KeychronQ9OrthoIntegrated.kicad_pcb]
2024-05-30 remove plating from encoder mounts
    [KeychronQ9OrthoIntegrated.kicad_pcb]
2024-05-30 fix silkscreen/solder mask conflicts
    [KeychronQ9OrthoIntegrated.kicad_pcb, KeychronQ9OrthoIntegrated.kicad_sch]
2024-05-30 update production files
    [bom.csv, positions.csv]
2024-05-30 add back right side numpad layout
    [KeychronQ9OrthoIntegrated.kicad_pcb, KeychronQ9OrthoIntegrated.kicad_sch, bom.csv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]
2024-05-30 fix spacebar routing
    [KeychronQ9OrthoIntegrated.kicad_pcb]
2024-05-30 route vias away from top case resting point
    [KeychronQ9OrthoIntegrated.kicad_pcb]
2024-06-01 add spacebar for 3u center cluster
    [KeychronQ9OrthoIntegrated.kicad_pcb, KeychronQ9OrthoIntegrated.kicad_sch, bom.csv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]
2024-06-01 add ortho plate subproject
    [KeychronQ9OrthoIntegrated.kicad_pcb, KeychronQ9OrthoIntegrated.kicad_sch, KeychronQ9OrthoPlate.kicad_pcb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]
2024-06-03 initial commit for q9-chimera multi-layout dropin
    [Q9-Chimera.kicad_pcb, Q9-Chimera.kicad_sch, q9chimera-plate.dxf]
2024-06-03 commit chimera and associated plate directory
    [Q9-Chimera-Plate-B_Cu.gbr, Q9-Chimera-Plate-B_Silkscreen.gbr, Q9-Chimera-Plate-Edge_Cuts.gbr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]
2024-06-04 unzip gerbers
    [KeychronQ9OrthoIntegrated-B_Courtyard.gbr, KeychronQ9OrthoIntegrated-B_Cu.gbl, KeychronQ9OrthoIntegrated-B_Fab.gbr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]
2024-06-07 added missing solder mask apertures and updated gerbers to reflect change
    [Q9-Chimera.kicad_pcb, bom.csv]
2024-06-26 reorganizing repo
    [KeychronQ9OrthoIntegrated-B_Courtyard.gbr, KeychronQ9OrthoIntegrated-B_Cu.gbl, KeychronQ9OrthoIntegrated-B_Fab.gbr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]
2024-06-26 update gerbers and kle
    [Q9-Chimera-B_Courtyard.gbr, Q9-Chimera-B_Cu.gbl, Q9-Chimera-B_Fab.gbr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]
2024-06-27 release prep
    [KeychronQ9OrthoIntegrated-B_Courtyard.gbr, KeychronQ9OrthoIntegrated-B_Cu.gbl, KeychronQ9OrthoIntegrated-B_Fab.gbr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]
2024-08-10 add 2 additional 2u footprints
2024-08-24 complete addition of 225/275 bars and associated tweaks
    [Q9-Chimera.kicad_sch]
2024-09-11 add new spacebar pcb stab cutouts to plate, except long bars
    [Q9-Chimera-Plate.kicad_pcb, Q9-Chimera-Plate.kicad_sch]
2024-09-15 split 225/275 to limousine, add 8u/10u support
    [Q9-Chimera-Plate.kicad_pcb, Q9-Chimera.kicad_sch]
2024-09-18 prep production files
    [Q9-Chimera-B_Courtyard.gbr, Q9-Chimera-B_Cu.gbl, Q9-Chimera-B_Fab.gbr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]
2024-09-18 swap conflicting sockets for solder/millmax
    [Q9-Chimera-B_Courtyard.gbr, Q9-Chimera-B_Cu.gbl, Q9-Chimera-B_Fab.gbr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]
2024-10-21 prep v1.1 release
    [Q9-Chimera.kicad_sch, bom.csv]
